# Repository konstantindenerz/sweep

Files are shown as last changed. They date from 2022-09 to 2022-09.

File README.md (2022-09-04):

# Sweep

## Hint to this repo

The reason for this fork is the custom themed `Sweep High (Synthwave)`:

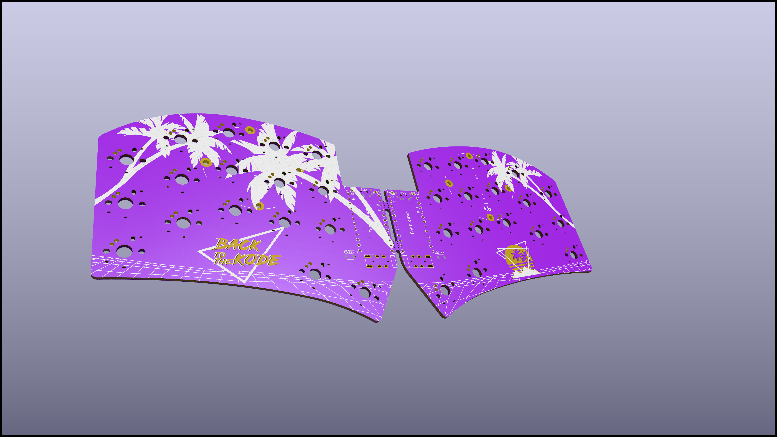
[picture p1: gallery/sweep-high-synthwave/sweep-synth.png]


## Original

| Front | Back |
| :---: | :---: |
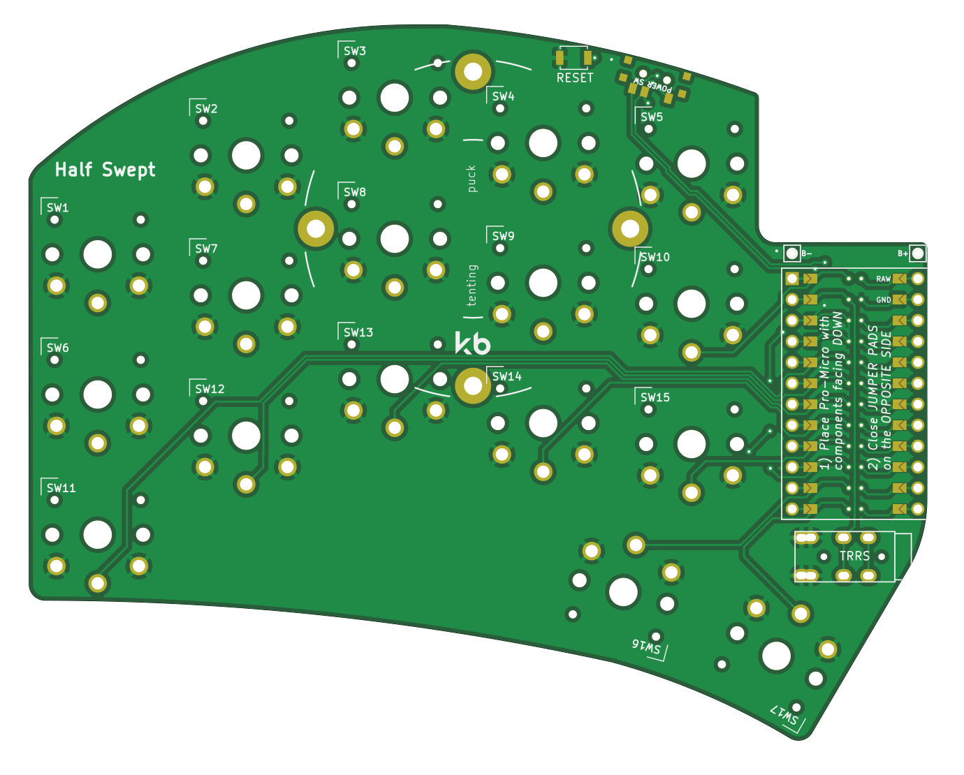
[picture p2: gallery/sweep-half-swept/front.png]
front
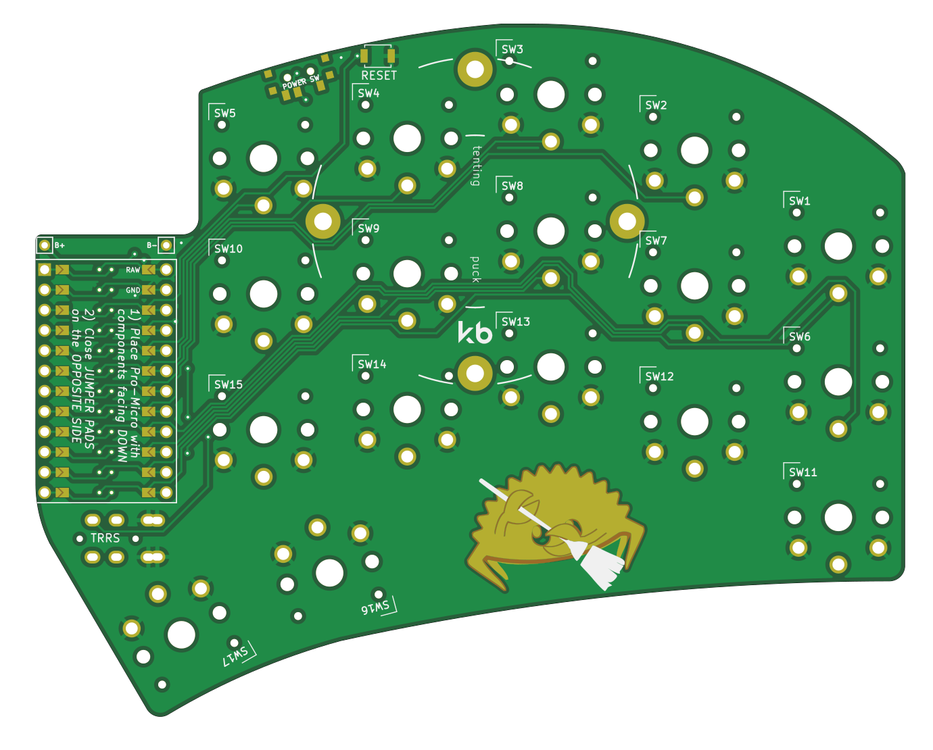
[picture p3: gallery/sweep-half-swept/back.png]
back
|  |  |

<span>
  <a href="https://discord.gg/czXcTXbsgU">
    
  </a>
  
</span>

## What is sweep?

Sweep is a version of the more fabulous [Ferris](https://github.com/pierrechevalier83/ferris) by [Pierre Chevalier](https://github.com/pierrechevalier83/) that uses a daughter board like a promicro, elite-c, bit-c, nice!nano etc. instead of using onboard components.

## What are the different types?

| Device | On/Off Switch<sup>[1]</sup> | Reversible PCB<sup>[2]</sup> | Choc V1 | Choc V2 | Choc Mini | MX & Alps | Choc Spacing<sup>[3]</sup> | Tenting<sup>[4]</sup> | Hot Swap |
| :--- | :---: | :---: | :---: | :---: | :---: | :---: | :---: | :---: | :---: |
| Sweep2.x | ✔ | | ✔ | | | | ✔ | ✔ | Mill-Max (optional) |
| Sweep Bling LP | ✔ | | ✔ | | | | ✔ | ✔ | Kailh (required) |
| Sweep Bling MX | ✔ | ✔ | | | | ⚠<br/><sup>[5]</sup> | | ✔ | Kailh (required) |
| Sweep High | ✔ | | ✔ | ✔ | | ✔ | | ✔ |
| Sweep Half Swept  | ✔ | ✔ | ✔ | | | | ✔ | ✔ | Mill-Max (optional) |
| Sweep Compact Low | | ✔ | | | ✔ | | ✔ | |

> Note: All versions support bluetooth with Nice!Nano

*<sup>[1]</sup> An on/off switch is recommended for bluetooth builds.*  
*<sup>[2]</sup> With a reversible PCB it's easier to make mistakes during assembly, but it allows you to purchase less boards.*  
*<sup>[3]</sup> Choc spaced boards have the switches in a tighter grid. This provides a better final look but is only compatible with some choc keycaps. (e.g. MBK)*  
*<sup>[4]</sup> Supports splitkb's [tenting puck.](https://splitkb.com/products/tenting-puck?_pos=1&_psq=tenting%20&_ss=e&_v=1.0)*  
*<sup>[5]</sup> MX + kailh hotswap ONLY. Alps are NOT supported.*  

* Sweep2 - Recommended Choc v1 board with all the features.
* Sweep Bling MX - An MX only Sweep that features Kailh's hotswap sockets and a stacked case.
* Sweep High - Same as the Sweep2 but trades choc spacing for compatibility with more switches and keycaps.
* Sweep Half Swept - Half of a Sweep2 with double pro-micro footprint (letting you avoid having one daughter-board flipped upside-down)
* Sweep Compact Low - The only version that supports Choc minis.

## Components list

To build and use a Sweep you will need:

* 1x PCB Kit
* 2x promicro compatible boards or 2 nice!nanos.
* 34 switches of a compatible type (refer to the compatibility table)
* 34 keycaps
* 2x reset switches (optional; [B3U-1000P(M)](https://github.com/davidphilipbarr/Sweep/issues/20))
* Some little rubber feet/bumpers
* 2x power switches (optional if supported; MSK 12C02)
* 1x TRRS (not TRS!) cable (wired build only)
* 2x TRRS Jack [PJ-320A] (wired build only)
* 1 USB Cable (depends on your micro-controller choice)

## How do I make this thing?

<a href="https://www.youtube.com/watch?v=fBPu7AyDtkM" target="_blank">
  
</a>

## Firmware

The firmware can be found [with the Ferris  firmware as part of QMK](https://github.com/qmk/qmk_firmware/tree/master/keyboards/ferris/sweep).

Firmware for zmk and bluemicro_ble is called ["Cradio"](https://zmk.dev/docs/hardware/).

## Who made this?

* [Pierre Chevalier](https://github.com/pierrechevalier83)
* [David Barr](https://github.com/davidphilipbarr)
* [Ibnu Daru Aji](https://github.com/ibnuda/)
* [Duccio](https://github.com/duckyb)

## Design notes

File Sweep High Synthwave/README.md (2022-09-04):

# Sweep HIGH
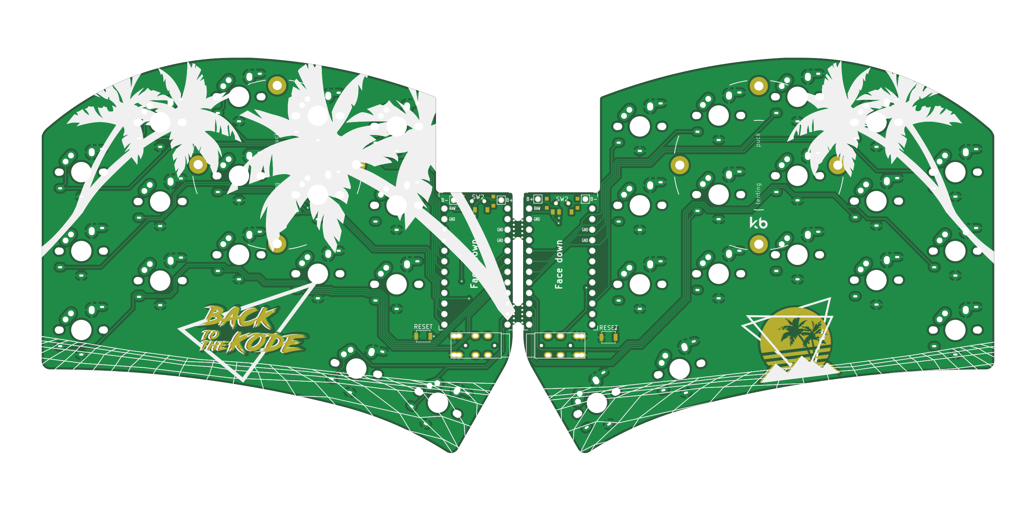
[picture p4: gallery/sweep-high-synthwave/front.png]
front

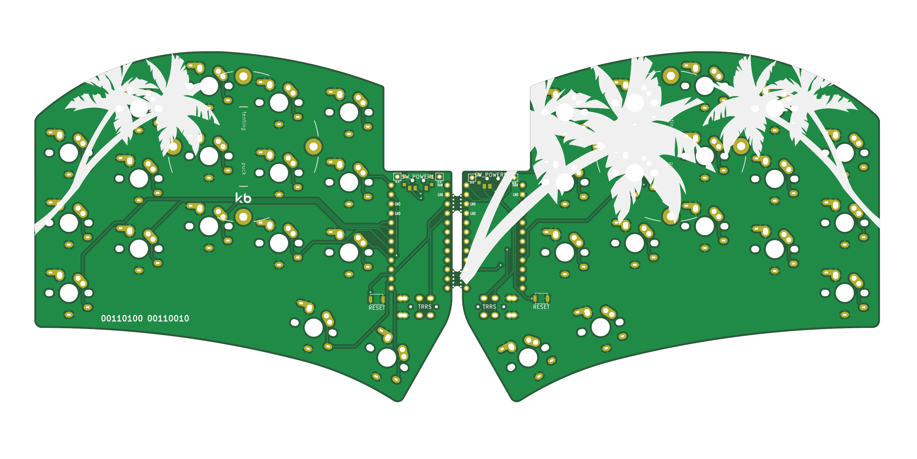
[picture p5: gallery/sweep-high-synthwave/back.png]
back


Same as the Sweep2 but trades choc spacing for compatibility with more switches and keycaps.

## Ordering The PCB

To order the PCB the following settings are recommended<sup>1,2</sup>: 

|Detail|Value|
|---|---|
|Gerber file|`sweep-high_gerber.zip`|
|Base material|FR-4|
|Layers|2|
|Dimension|95.15mm x 229.54mm|
|Different design|2|
|Delivery format|Panel by customer|
|PCB thickness|1.6mm|
|PCB color|purple|
|Silkscreen|(Personal preference)|
|Surface finish|(Personal preference)|
|Outer copper weight|1oz|
|Gold Fingers|No|
|Confirm production file|No|
|Castellated holes|No|
|Remove order number|Yes|

1: Settings are for [JLCPCB](https://jlcpcb.com/), but could work for other manufacturers.

2: Settings are taken from [Kyek's video guide](https://www.youtube.com/watch?v=fBPu7AyDtkM&t=17s).

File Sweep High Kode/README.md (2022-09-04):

# Sweep HIGH
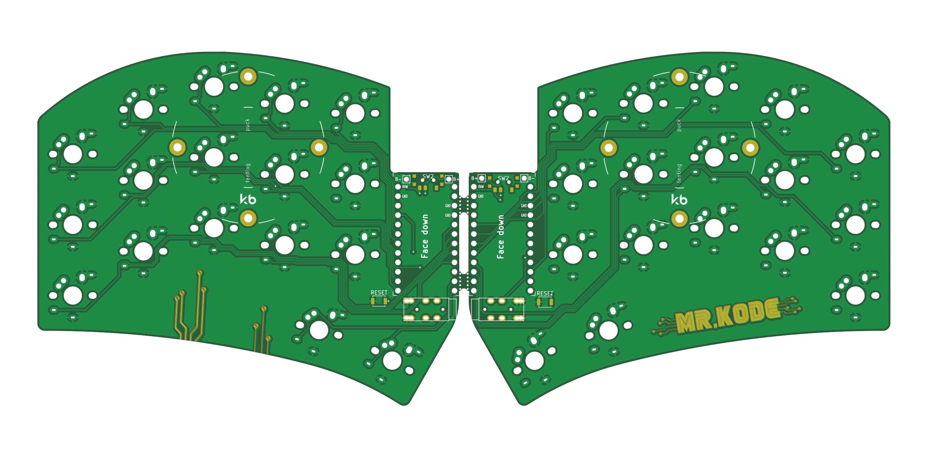
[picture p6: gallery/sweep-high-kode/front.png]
front

back

Same as the Sweep2 but trades choc spacing for compatibility with more switches and keycaps.

## Ordering The PCB

To order the PCB the following settings are recommended<sup>1,2</sup>: 

|Detail|Value|
|---|---|
|Gerber file|`sweepv2.1_gerber.zip`|
|Base material|FR-4|
|Layers|2|
|Dimension|95.15mm x 229.54mm|
|Different design|2|
|Delivery format|Panel by customer|
|PCB thickness|1.6mm|
|PCB color|(Personal preference)|
|Silkscreen|(Personal preference)|
|Surface finish|(Personal preference)|
|Outer copper weight|1oz|
|Gold Fingers|No|
|Confirm production file|No|
|Castellated holes|No|
|Remove order number|Yes|

1: Settings are for [JLCPCB](https://jlcpcb.com/), but could work for other manufacturers.

2: Settings are taken from [Kyek's video guide](https://www.youtube.com/watch?v=fBPu7AyDtkM&t=17s).

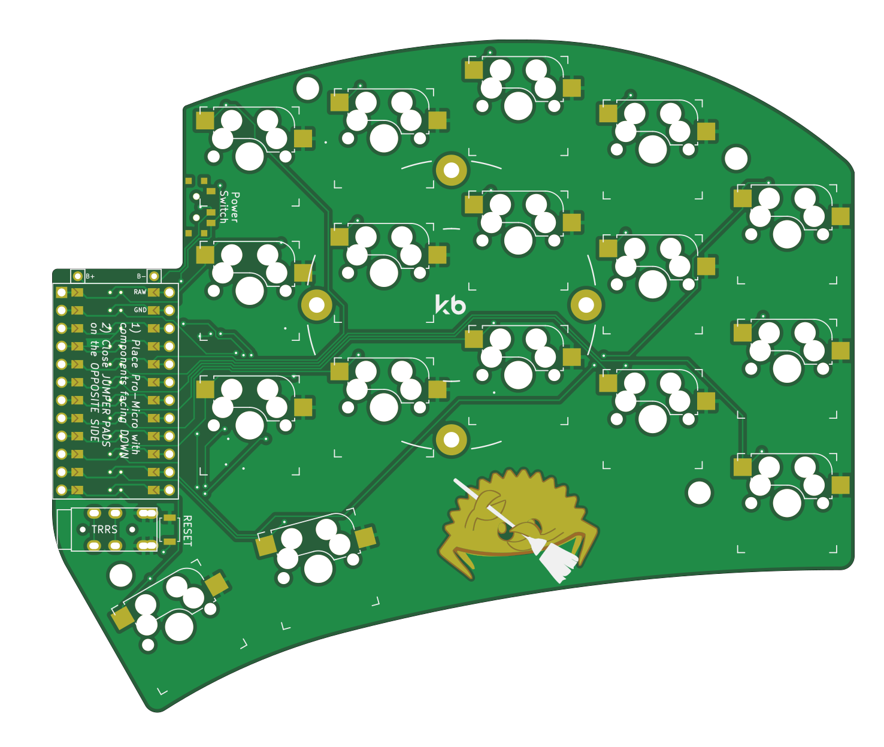
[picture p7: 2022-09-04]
gallery/sweep-bling-mx/back.png

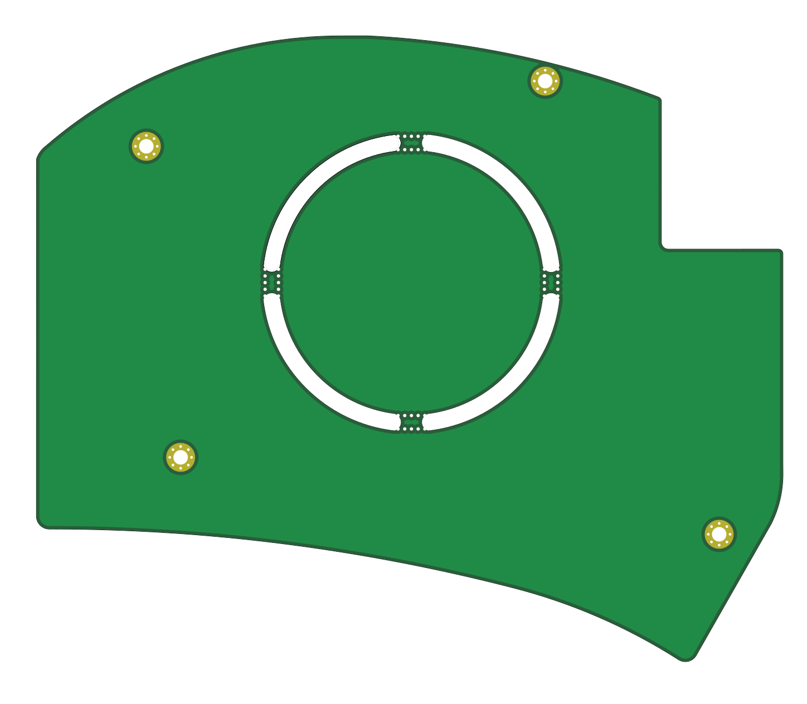
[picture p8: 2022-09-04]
gallery/sweep-bling-mx-bottom/front.png

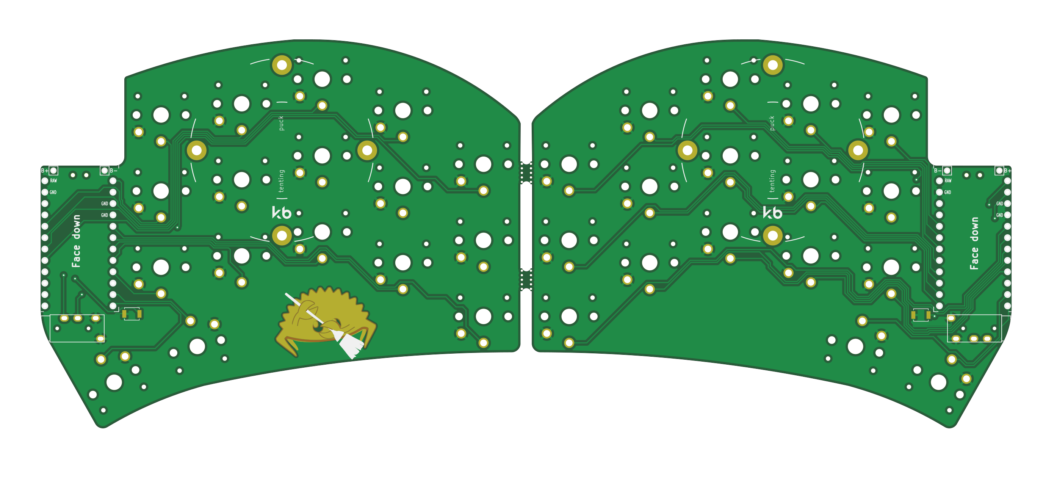
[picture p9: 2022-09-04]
gallery/sweepv2/front.png

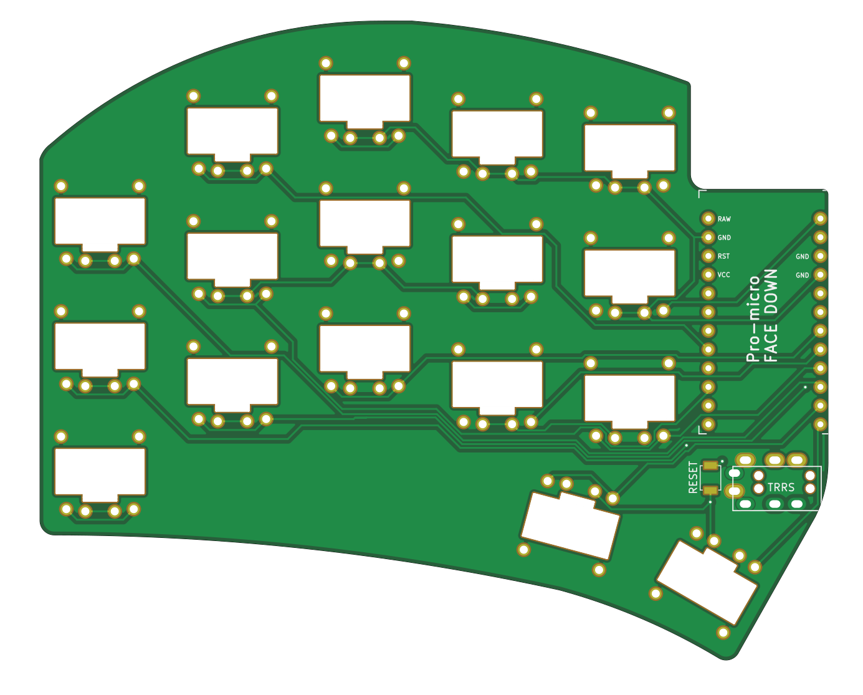
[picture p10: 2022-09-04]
gallery/sweep-compact-low/front.png

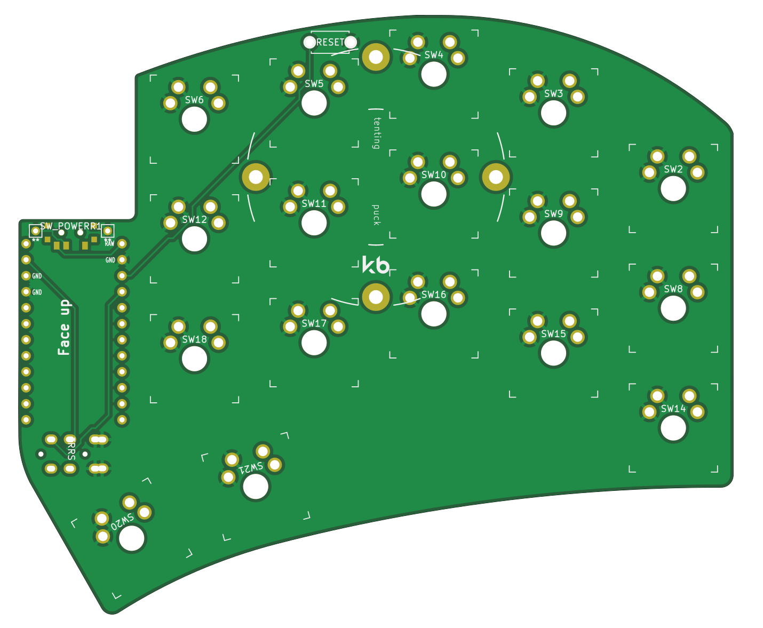
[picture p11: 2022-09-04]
gallery/sweep-high-m/back.png

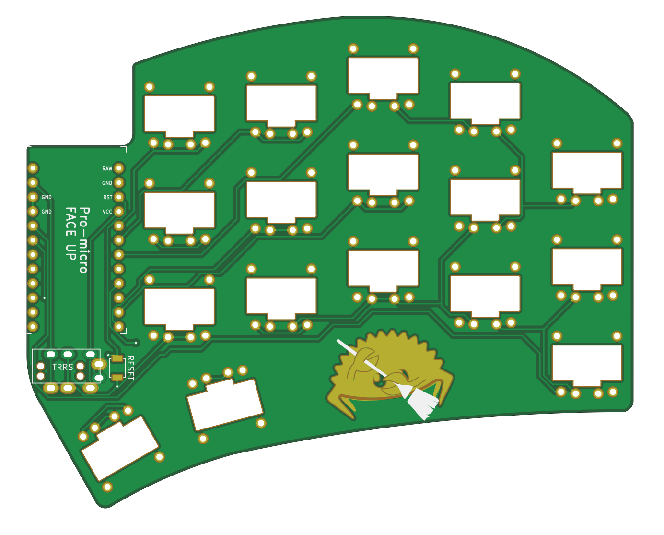
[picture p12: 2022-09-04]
gallery/sweep-compact-low/back.png

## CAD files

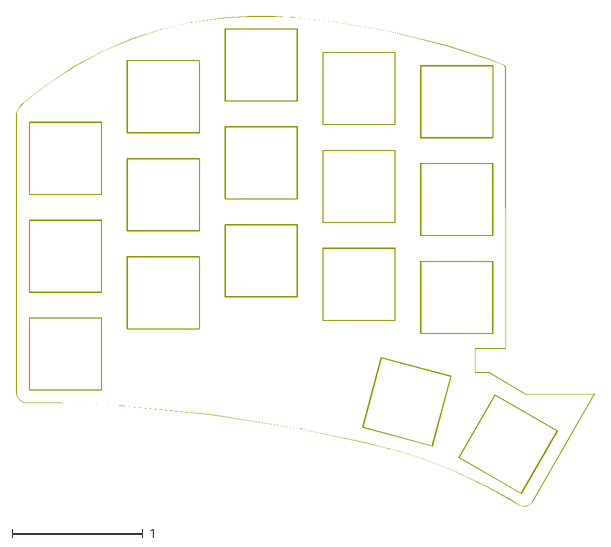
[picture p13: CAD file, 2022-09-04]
Sweep High Kode/sweep-high-top-plate.dxf
4.42 x 3.75

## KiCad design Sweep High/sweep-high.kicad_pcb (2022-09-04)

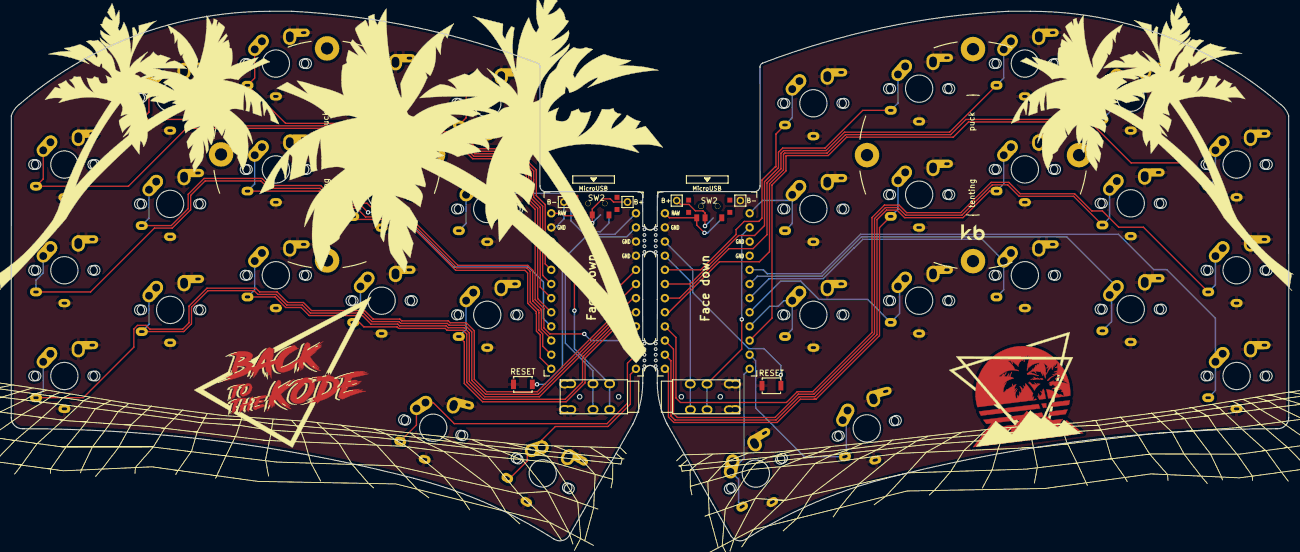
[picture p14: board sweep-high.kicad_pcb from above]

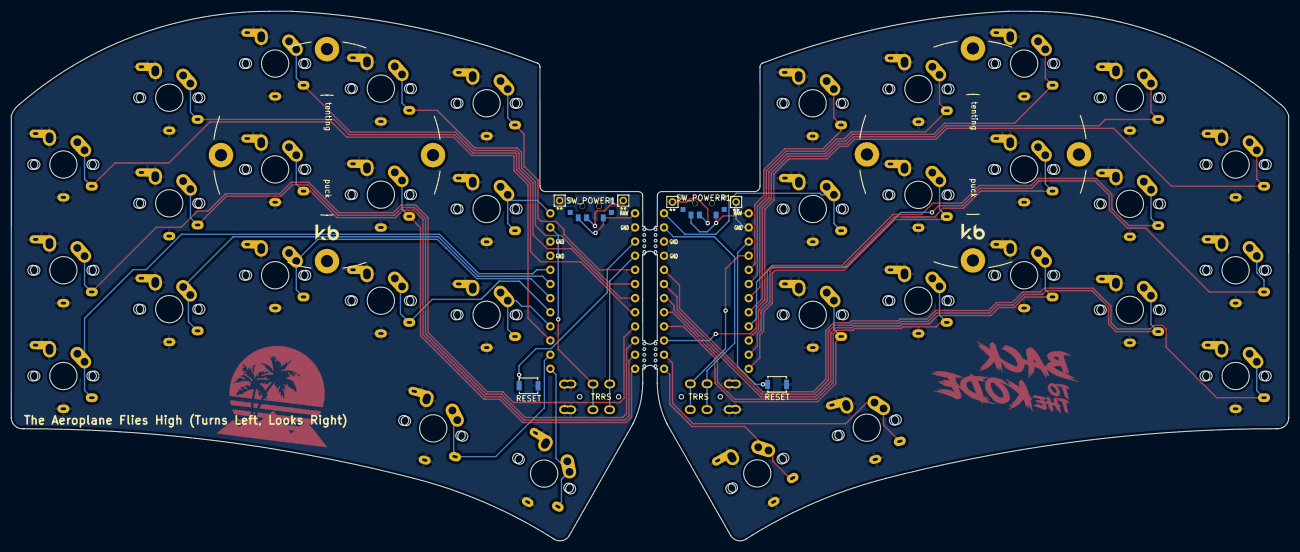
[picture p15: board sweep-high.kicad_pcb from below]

Board: 2 copper layers, 229.5 x 95.2 mm, 52 parts (4 on the bottom side), 43 nets.

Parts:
B+: MountingHole_Pad; 1pin_conn
B+#2: MountingHole_Pad; 1pin_conn
B-: MountingHole_Pad; 1pin_conn
B-#2: MountingHole_Pad; 1pin_conn
J1, J2: AudioJack4dpb; TRRS-PJ-DPB2
RSW1, RSW1#2, RSW2, RSW2#2: SW_Push; SW_SPST_B3U-1000P
SW2, SW2_r1, SW3, SW3_r1, SW4, SW4_r1, SW5, SW5_r1, SW6, SW6_r1, SW7_r1, SW8, SW8_r1, SW9, SW9_r1, SW10, SW11, SW11_r1, SW12, SW12_r1, SW13_r1, SW14, SW15, SW15_r1, SW16, SW16_r1, SW17, SW17_r1, SW18, SW18_r1, SW20, SW20_r1, SW21, SW21_r1: SW_Push; keyswitch_cherrymx_alps_choc12_slots_1u
SW2#2, SW2#3: SW_SPDT; SPDT_C128955r
SW_POWER1: SW_SPDT; SPDT_C128955
SW_POWERR1: SW_SPDT; SPDT_C128955
U1, U2: ProMicro-kbd; ProMicro_v3_min
mouse-bite-5mm-slot, mouse-bite-5mm-slot#2: VAL**; mouse-bite-5mm-slot-with-space-for-track

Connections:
BT+: B+#2.1, SW2#3.2, SW_POWER1.2
BT+_r: B+.1, SW2#2.2, SW_POWERR1.2
Switch1: SW2.1, U1.10
Switch1_r: SW2_r1.1, U2.10
Switch2: SW3.1, U1.17
Switch2_r: SW3_r1.1, U2.17
Switch3: SW4.1, U1.18
Switch3_r: SW4_r1.1, U2.18
Switch4: SW5.1, U1.19
Switch4_r: SW5_r1.1, U2.19
Switch5: SW6.1, U1.20
Switch5_r: SW6_r1.1, U2.20
Switch6: SW8.1, U1.16
Switch6_r: SW7_r1.1, U2.16
Switch7: SW9.1, U1.15
Switch7_r: SW8_r1.1, U2.15
Switch8: SW10.1, U1.14
Switch8_r: SW9_r1.1, U2.14
Switch9: SW11.1, U1.13
Switch9_r: SW11_r1.1, U2.13
Switch10: SW12.1, U1.1
Switch10_r: SW12_r1.1, U2.1
Switch11: SW14.1, U1.5
Switch11_r: SW13_r1.1, U2.5
Switch12: SW15.1, U1.6
Switch12_r: SW18_r1.1, U2.6
Switch13: SW16.1, U1.7
Switch13_r: SW15_r1.1, U2.7
Switch14: SW17.1, U1.8
Switch14_r: SW16_r1.1, U2.8
Switch15: SW18.1, U1.9
Switch15_r: SW17_r1.1, U2.9
Switch16: SW21.1, U1.11
Switch16_r: SW21_r1.1, U2.11
Switch17: SW20.1, U1.12
Switch17_r: SW20_r1.1, U2.12
Switch18: J2.R1, U1.2
Switch18_r: J1.R1, U2.2
gnd: B-.1, B-#2.1, J1.S, J1.T, J2.S, J2.T, RSW1.1, RSW1#2.1, RSW2.1, RSW2#2.1, SW2.2, SW2_r1.2, SW3.2, SW3_r1.2, SW4.2, SW4_r1.2, SW5.2, SW5_r1.2, SW6.2, SW6_r1.2, SW7_r1.2, SW8.2, SW8_r1.2, SW9.2, SW9_r1.2, SW10.2, SW11.2, SW11_r1.2, SW12.2, SW12_r1.2, SW13_r1.2, SW14.2, SW15.2, SW15_r1.2, SW16.2, SW16_r1.2, SW17.2, SW17_r1.2, SW18.2, SW18_r1.2, SW20.2, SW20_r1.2, SW21.2, SW21_r1.2, U1.3, U1.4, U1.23, U2.3, U2.4, U2.23
raw: SW2#2.3, SW2#3.3, SW_POWER1.3, SW_POWERR1.3, U1.24, U2.24
reset: RSW1.2, RSW1#2.2, U1.22
reset_r: RSW2.2, RSW2#2.2, U2.22
vcc: J1.R2, J2.R2, U1.21, U2.21

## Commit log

2022-09-03 feat(synthwave): add palms and sun
    [sweep-high.kicad_pcb]
2022-09-03 update preview
    [sweep-high.kicad_pcb]
2022-09-04 update left side branding
    [sweep-high.kicad_pcb]
2022-09-04 create new sweep high copy with kode theme
    [sweep-high-top-plate.dxf, sweep-high.sch, sweep-high_plate.kicad_pcb]
